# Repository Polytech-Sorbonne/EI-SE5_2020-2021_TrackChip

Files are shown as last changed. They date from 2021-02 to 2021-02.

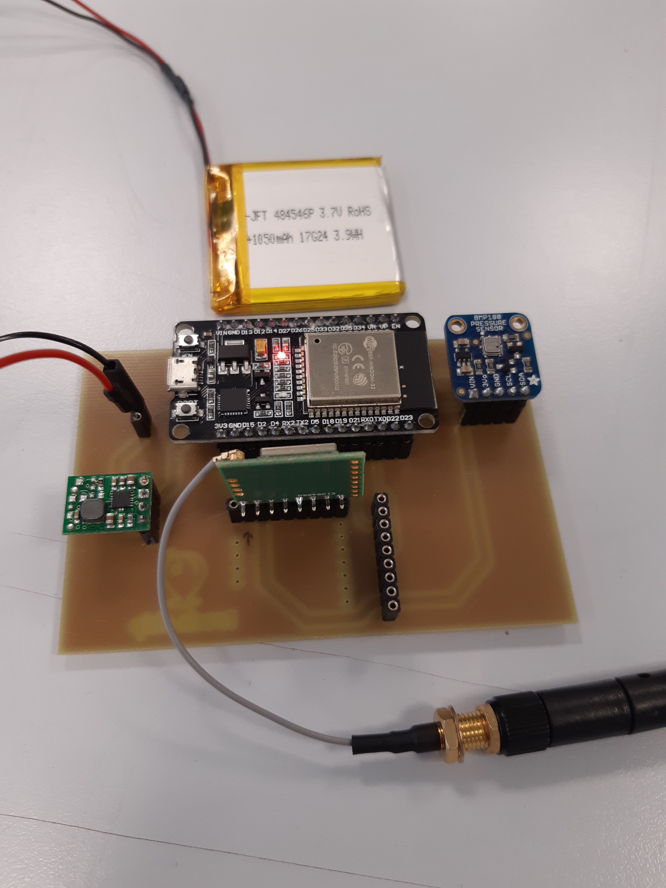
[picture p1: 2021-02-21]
ressources/pictures/pcb_front2.jpg

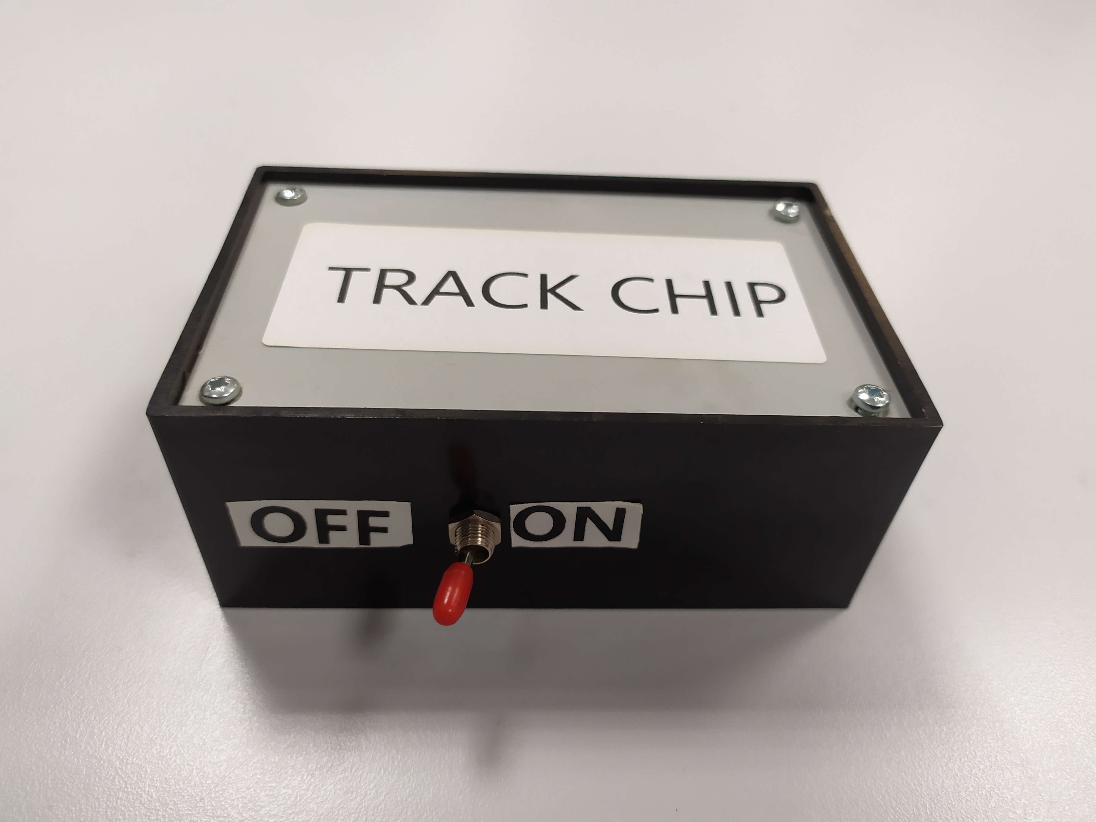
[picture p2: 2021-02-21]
ressources/pictures/integrated_system.jpg

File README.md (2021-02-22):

# TrackChip, le traqueur autonome ! 
L'objectif de ce projet est double :
* Développer un traqueur autonome de précision ~10m (partie Device)
* Récupérer ces informations sur un client WEB (partie Cloud)

### Device
Le device en lui-même est basé sur un micro-controleur ESP32, entouré des périphériques suivant :
* Altimètre BMP180
* GPS ADA746
* Module Sigfox BRKWS01
* Batterie LIPO 1050mAh
* Régulateur de tension 5V Polulu U1V11F5

```
Les sources des bibliothèques des périphériques ainsi que du PCB sont disponibles dans le dossier /devices du git.
```
### Site Web
Le site internet possède les fonctionnalitées suivantes :
* Position de l'utilisateur
* Position du traqueur
* Calcul de la différence d'altitude
* Calcul du trajet en voiture pour rejoindre le traqueur
* Historique des positions du traqueur

```
Les sources du serveur, de la base de donnée et du site Web sont disponibles dans la partie cloud/ du git.
```

# Notice d'utilisation
Le système dans son ensemble possède le comportement suivant :
* Le device utilise le GPS quand il reçoit un signal
* Le device utilise le scrapping WiFi quand le GPS est indisponible
* La position est envoyée sur notre serveur via le réseau SigFox
* Les informations sont accessibles sur notre site via un client Web. 

### Device
Le device s'allume et s'éteint avec le boutton ON/OFF sur le côté de sa boîte protectrice.
Il envoie alors sa position toutes les 5 minutes.
```
Le programme faisant fonctionner le device peut-être modifié et téléversé avec l'IE Arduino.
Il faut simplement s'assurer que les librairies utilisées sont bien visibles en les ajoutant dans ~/Arduino/lib.
```

### Réseau SigFox
Le device envoie ses données sur un backend web en utilisant le réseau SigFox.
Ce backend redirigie ensuite ces informations sur notre serveur grâce à une fonction de callback.
On accède au backend via l'URL suivant :
```
https://backend.sigfox.com/auth/login
```

### Serveur
Le serveur est un ensemble de programmes gérant le site Web ainsi que la base de donnée. 
Il peut être hebergé sur une machine locale, ou bien sur internet via un VPS.
Afin d'avoir accès aux nombreux service de géolocalisation (carte, itinéraire, etc), nous avons utilisé différentent APIs fournit par Google.
Ces APIs nécéssitent une clés pour pouvoir y accéder que vous devrez générer en créant d'abord un compte Google Cloud Platform. 
Puis en copiant, collant votre clés à la place de la notre dans le fichier dev/cloud/php/map.php à la ligne 44 dans le lien du script.
En local, on peut lancer le site avec les commandes suivantes :
```
$ cd /path/to/sources
$ php -S 127.0.0.1.:8888
```

### Site Web
Nous avons choisi d'utiliser l'hébergeur always-data pour notre site.
Cela donnait un URL du type :
```
https://track-chip.alwaysdata.net/
```

# Démonstration

Nous avons réalisé une petite vidéo de démonstration pour notre projet que vous pouvez visionner via les liens suivants : 
```
https://youtu.be/R3p7xfixrZM
https://drive.google.com/file/d/12YnQqh70TEWXKH5hvB63JBAPzKjCPeCU/view?usp=sharing
```

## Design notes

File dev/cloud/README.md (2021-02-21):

# Procédure à suivre pour se connecter au site

Ouvrir un navigateur internet (Chrome ou Chromium de préférence, ne fonctionne pas sur Safari) et taper l'adresse suivante : 
```
https://track-chip.alwaysdata.net/cloud/php/map.php
```

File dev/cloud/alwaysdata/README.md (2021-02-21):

# Procedure à suivre pour créer une cles SSH sur le serveur AlwaysData

## Etape 1 :

Générer la clé en local.
		
		$ mkdir -p $HOME/.ssh
		$ chmod 0700 $HOME/.ssh
		$ ssh-keygen -t ed25519 -f $HOME/.ssh/id_ed25519
		
		(tips : vous pouvez indiquez une passphrase vide pour pouvoir vous connecter directement sans la rentrer)

## Etape 2 :

Déclarer la clés publique (.pub) sur le serveur.

		$ ssh-copy-id -i $HOME/.ssh/id_ed25519.pub track-chip@ssh-track-chip.alwaysdata.net

## Etape 3 :

Se connecter au serveur en ssh.

		$ ssh track-chip@ssh-track-chip.alwaysdata.net

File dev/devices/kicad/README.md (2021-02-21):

# KiCad - Architecture

## Librairie
```
Le fichier track_chip.lib contient tout les "symboles" créés pour le projet :
	- ESP32 NodeMCU
	- BMP180
	- ADA746
	- BRKWS01

La librairie contient aussi les symboles déjà présents par défaut dans KiCad, 
afin d'éliminer la dépendance à la version du logiciel.
```

## Schéma
```
Le fichier .sch représente le schéma du circuit électronique du système (Eeschema).
Il instancie les différents symboles de la librairie du projet.
```

## Empreintes

### Dimensions
```
- Largeur typique d'une piste : 1mm
- Largeur typique d'une alimentation : 2mm
- Ecart entre les pastilles : 2.54mm
- Diamètre typique de perçage : 0.8mm
- Diamètre typique de pastille : 1.5mm
```

### Plans de masse
```
Recommendations : faire des plans de masses.
Si il y a un domaine analogique et un domaine numérique, 
faire des plans de masse séparés et les relier avec une piste.
```

## Batterie
```
On utilise un circuit avec chargeur intégré.
```
# Version Sigfox
La version Sigfox utilise un module Wisol pour les communications.
C'est cette version qui a été retenue pour les démonstrations

# Version GSM
La version GSM utilise une carte SIM pour les communications.
Cette version est en cours de développement.

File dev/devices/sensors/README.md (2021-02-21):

# Sensors
```
Dossier contenant les librairies pour les différents capteurs.
```

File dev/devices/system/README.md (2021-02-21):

# Classe track_chip
Classe encapsulant les librairies pour les différents périphériques.
(Communication, capteurs, position etc ...)

# Précaution lors de l'upload du code 
Il faut débrancher le broche TX du GPS pour pouvoir téléverser le code depuis l'IDE arduino.
C'est parce que ce gps utilise le même port série que le calbe USB utilisé pour téléverser.

# Architecture du code 
* On utilise la liaison _Serial_ pour imprimer des caractères sur la liaison USB

* Le gps communique avec la liaison _Serial1_ sur les broches RX0 et TX0 de l'ESP32
	+ BAUDE=9600 par défaut

* Le wisol communique avec la liaison _Serial2_ sur les broches RX2 et TX2 de l'ESP32 
	+ BAUDE=9600 par défaut

# examples/class_system/
Ce dossier instancie un code example utilisant la classe track_chip
(En cours de développement)

# examples/bare_system/
Ce dossier instancie un code example utilisant les libairies sans la classe track_chip

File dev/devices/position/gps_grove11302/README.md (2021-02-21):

# Module GPS Grove

Le dossier grove11302/ contient une librairie Arduino pour l'utilisation du module GPS Grove 11302..
Pour utiliser cette librairie, compresser ce dossier en .zip puis l'ajouter dans l'IDE dans sketch -> include librairy

Le dossier examples/ contient 2 codes sources Arduino permmetant d'imprimer sur une liaison série les données brut provenant du module GPS puis uniquement la ligne de donnée comportant les coordonnées en DMS (degrés , minutes, secondes).

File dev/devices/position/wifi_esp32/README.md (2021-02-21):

# Fonctions de localisation grâce aux réseaux Wifi
```
Ces fonctions ont été recopiées et intégrées à la classe TrackChip.
```

# Installation instructions using Arduino IDE Boards Manager
```
- Stable release link: `https://raw.githubusercontent.com/espressif/arduino-esp32/gh-pages/package_esp32_index.json`
- Development release link: `https://raw.githubusercontent.com/espressif/arduino-esp32/gh-pages/package_esp32_dev_index.json`

Starting with 1.6.4, Arduino allows installation of third-party platform packages using Boards Manager. We have packages available for Windows, Mac OS, and Linux (x86, amd64, armhf and arm64).

- Install the current upstream Arduino IDE at the 1.8 level or later. The current version is at the [Arduino website](http://www.arduino.cc/en/main/software).
- Start Arduino and open Preferences window.
- Enter one of the release links above into *Additional Board Manager URLs* field. You can add multiple URLs, separating them with commas.
- Open Boards Manager from Tools > Board menu and install *esp32* platform (and don't forget to select your ESP32 board from Tools > Board menu after installation).
```

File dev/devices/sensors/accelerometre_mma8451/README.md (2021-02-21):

# Accéléromètre MMA8451

## BUS I2C
```
Deux fils (SDA, SCL) tirés à 5V.

I2C utilise des séquences de 8 bits (MSB first = Big Endian)

Start - slave_addr - A - slave_reg - A - Data - A - Stop

Start	: SDA drops low, SDC still high
ACK	: le slave tire la ligne SDA à zéro
Stop 	: SDA low -> high ; SCL high
```

## Librairie utilisée
```
https://github.com/adafruit/Adafruit_MMA8451_Library
```

## Packager la librairie modifiée
```
Créer un lien symbolique du dossier mma8451/ dans Arduino/libraries :
$ cd ~/Arduino/libraries
$ ln -s /path/to/mma8451
```

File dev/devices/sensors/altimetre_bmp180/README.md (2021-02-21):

# Altimètre BMP180

## BUS I2C
```
Deux fils (SDA, SCL) tirés à 5V.

I2C utilise des séquences de 8 bits (MSB first = Big Endian)

Start - slave_addr - A - slave_reg - A - Data - A - Stop

Start	: SDA drops low, SDC still high
ACK	: le slave tire la ligne SDA à zéro
Stop 	: SDA low -> high ; SCL high
```

## Librairie utilisée
```
https://bitbucket.org/christandlg/bmp180mi/src/master/
```

## UML
```
Cette librairie possède le diagramme UML suivant :
		BMP180MI 
		   |
		   |
	     BMP180TwoWire 
		   |
		   |
	       BMP180I2C

On se contente donc de modifier la classe fille BMP180I2C
```

## Packager la librairie modifiée
```
Créer un lien symbolique du dossier bmp180/ dans Arduino/libraries :
$ cd ~/Arduino/libraries
$ ln -s /path/to/bmp180
```

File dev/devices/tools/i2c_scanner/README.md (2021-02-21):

# Scanner I2C
```
Ce code (tiré du site d'Arduino) permet de scanner les différents périphériques I2C.
Dès qu'un périphérique est branché au BUS I2C de notre µControleur, ce code affiche son addresse 0x...
```

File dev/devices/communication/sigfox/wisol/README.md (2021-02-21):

Guide Utilisation librairie Wisol
developpée pour module Wisol Sigfox et ESP32 
Pour utiliser la librairies :
compresser le dossier wisol au format .zip puis ajouter depuis l'IDE: sketch > include library

Pour utiliser l'example sans mdofications :
TX (wisol) -> RX2 (esp32)
RX (wisol) -> TX2 (esp32)
+ (wisol) -> 3.3V (esp32)
- (wisol) -> GND (esp32)

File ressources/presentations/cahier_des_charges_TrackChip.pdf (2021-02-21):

Cahier des Charge : TrackChip

- Contexte

Ce projet se déroule dans le cadre de notre 5ᵉ année au sein de l'école d'ingénieurs Polytech Sorbonne, en spécialité électronique et informatique embarquée. Nous devons donc ici développer un objet connecté répondant à un problème concret.

- Cas d’usages

Le but est de pouvoir localiser précisément votre bagage, votre véhicule ou bien même des personnes partout dans le monde ce qui pourrait être une bonne solution en cas de vol ou de perte.

De plus, avec l’explosion du commerce en ligne et la dématérialisation des espaces de travail, les envois de colis se sont multipliés. Il existe une part d’ombre à ce phénomène : les colis volés et perdus ou endommagés. Les entreprises communiquent peu sur le sujet mais on estime à 1.5 millions de colis traités par La Poste qui "disparaissent" chaque année. Ce n’est guère mieux pour Amazon où 17% des produits arrivent endommagés chez le client. Dans le cadre d’objets fragiles et/ou de grande valeurs marchande, placer un boîtier enregistrant les déplacements et les chocs subis par un paquet permet au livreur ou au vendeur de localiser la précieuse cargaison et de documenter les conditions de transport pour améliorer l’acheminement.

- Acteurs

Étudiants : Thomas Bouix, Aziz Idomar, Enzo Calvino, Eugène Raphanel Référent : Roselyne Chotin
Support Technique : Sylvain Viateur
- Nom du projet
TrackChip, le traqueur de poche !
- Besoins
- Localiser précisément un bagage / colis
- Connaître la vitesse de ce bagage / colis
- Connaître l’altitude de ce bagage / colis
- Connaître les collisions subit par ce bagage / colis

- Matériel nécessaire

Micro-Controlleur :

- ESP32 (https://www.gotronic.fr/art-module-nodemcu-esp32-28407.htm)

Communication :
- Module Wisol SigFox

Capteurs :

- GPS (https://www.gotronic.fr/art-module-gps-ada746-20694.htm)
- Altimètre (https://www.gotronic.fr/art-capteur-de-pression-mpl3115a2-20239.htm#complte_desc)
- Accéléromètre (https://www.gotronic.fr/art-accelerometre-et-gyroscope-3-axes-sen-mpu6050-31492.htm)

Alimentation :

- Batterie (https://www.gotronic.fr/art-accu-lipo-3-7-vcc-4000-mah-l805080-31843.htm)
- États de l’art
- Solutions déjà existantes
Spotter : 90€ + Abonnement (5€/mois)
→ Géolocalisation, appels, zone de sécurité

Invoxia : 99 € avec application et assistance
→ Tracker GPS pour Véhicule, Personne et Objets Précieux
- Valeur Ajoutée
- Altitude, Collisions
- Prix du traqueur : proposer les mêmes fonctionnalités pour un prix inférieur.
- Minimal Viable Product
- Organisation

Nous allons réaliser le projet en suivant une méthode agile. Nous avons donc établi plusieurs étapes de notre produit qui seront de plus en plus développées au cours du projet. Pour chaque étape, nous avons rédigé des Users Stories, c'est-à-dire des petits cas d’usage qui seront développés de manières indépendante au cours d’un sprint.
Les étapes 1 et 2 correspondent au développement de notre MVP :

Etape 1 : Fonctionnement local
- Position, Altitude, Accélération dans un terminal
- US : récupérer l’altitude dans un terminal série.
- US : récupérer l’accélération dans un terminal série.
- US : récupérer la position avec le GPS
- US : faire le schéma électrique (Kicad)
- US : intégrer toutes les solutions (sur labdec)

Etape 2 : Communication avec l’extérieur
- Position, altitude et accélération en raw dans un site web html simple
- US : Définir la base de données (draw.io + fichier sql)
- US : Créer un serveur web simple pouvant récupérer des données (Framework + HTML)
- US : Configurer le backend SigFox
- US : Configurer la communication GSM
- US : Envoyer les données en utilisant Sigfox (vérifier avec printf ESP32)
- US : Envoyer les données en utilisant la communication GPRS
- US : Choix du protocole de communication en fonction des résultats
- US : Lier la base de donnée au site web
- US : Récupérer les données Sigfox / GPRS sur un serveur web
- US : Créer une carte électronique (PCB)
- US : Envoyer les données de la machine sur le serveur
- US : Intégrer les composants sur la carte

Pour déterminer notre MVP, nous avons fait la liste des fonctionnalités et usages pouvant être utiles à notre projet. Ensuite nous les avons classifiés selon 3 degrés d’importance. Les fonctionnalités en vert (voir ci-dessous) sont celles que nous jugeons indispensables et que nous allons donc intégrer au MVP.

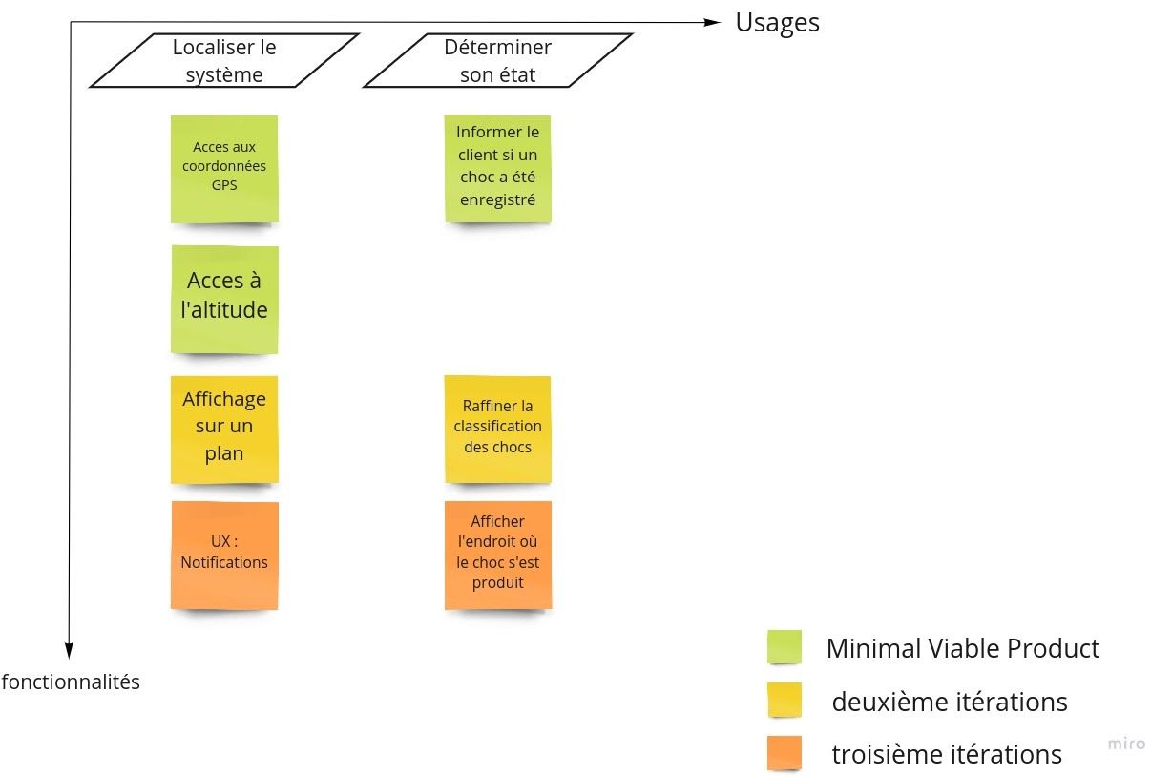
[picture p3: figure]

Usages et fonctionnalités du produit

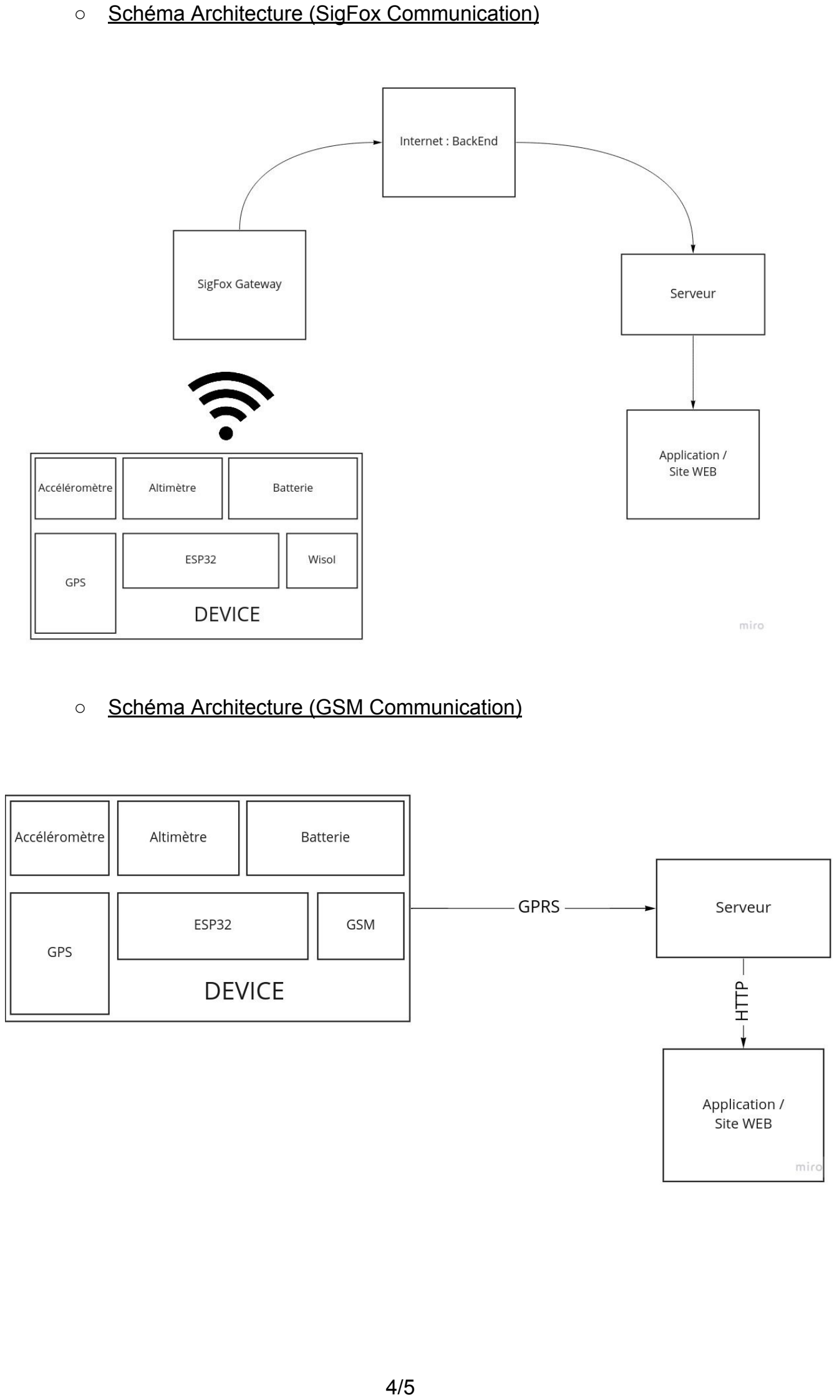
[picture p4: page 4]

- Schéma Architecture (SigFox Communication)
- Schéma Architecture (GSM Communication)

ANNEXE

Calcul théorique de la consommation

Approximation des consommation :
- ESP32 = 50 mA pendant 15s (3,8 mA avec clock ralentie)
- GPS = 20mA pendant 10s
- Wisol = 20mA pendant 15s
- Accéléromètre & Altimètre ~ 1 mA pendant 15s
- Système complet = 0 mA en veille

À une fréquence de 1 fois toutes les 10 minutes

Consommation par heure
= (50 mA*15s + 21mA * 15s + 20mA*10s) * 6
= 7,6As (ou 7,6C)

Avec une batterie de capacité 4Ah ou 4*3600C = 14,4kC Nombre d’heures de fonctionnement théorique :
Nbh = 14,4k / 7,6 = 1895h = 79j

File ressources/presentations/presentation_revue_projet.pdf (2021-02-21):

# Projet IOT Présentation d’un prototype

TrackChip, le traqueur de colis !

Eugène Raphanel, Enzo Calvino, Aziz Idomar, Thomas Bouix

II/ Présentation du projet

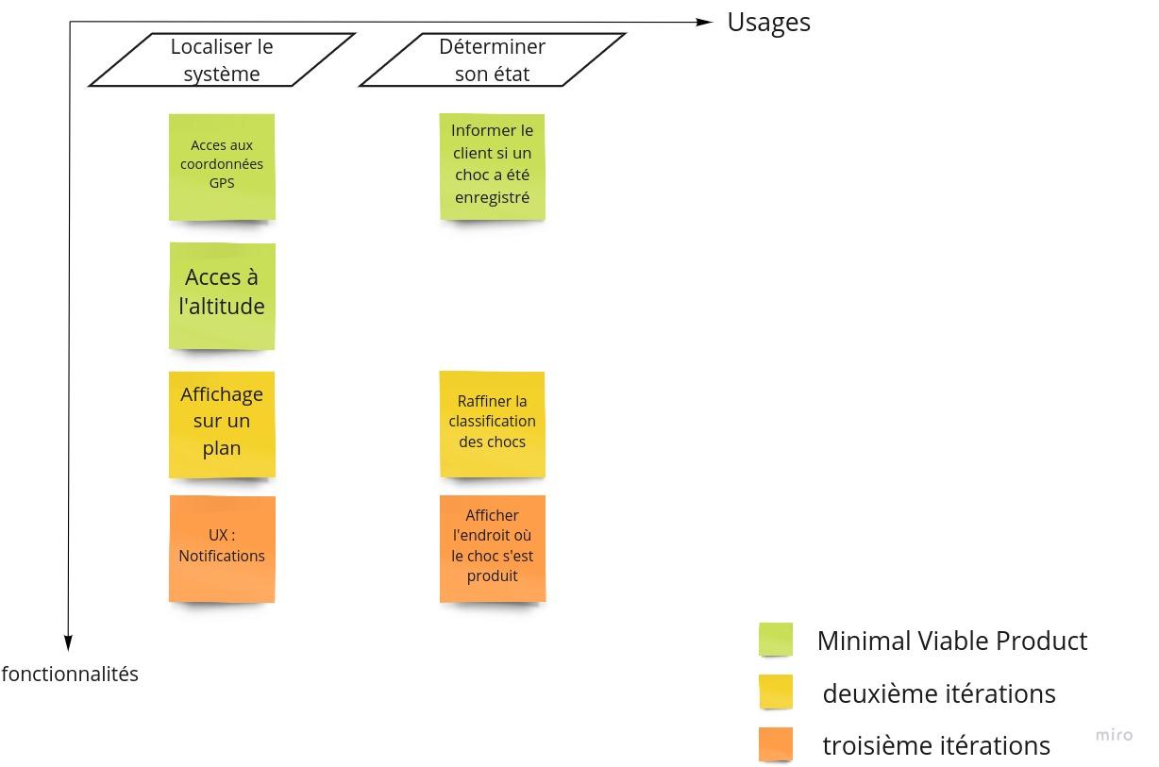
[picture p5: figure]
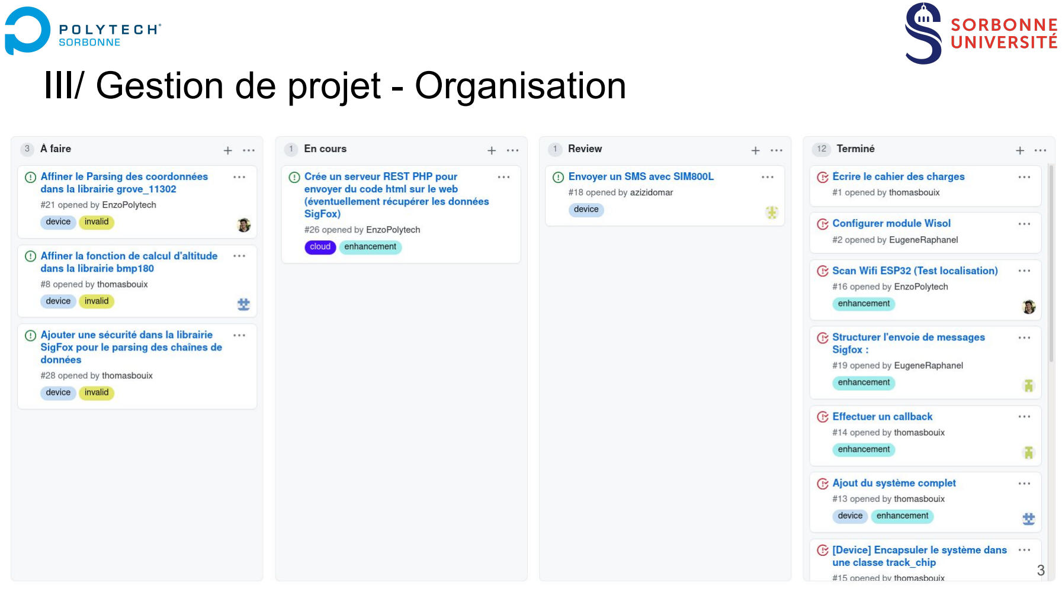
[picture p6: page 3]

III/ Gestion de projet - Organisation

IV/ Système - Partie “Device”

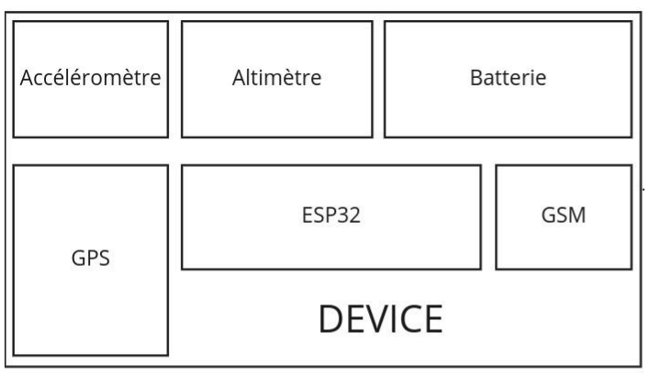
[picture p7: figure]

ESP32
Altimètre
Accéléromètre
GPS
GSM
Batterie

IV/ Système - Communication SigFox

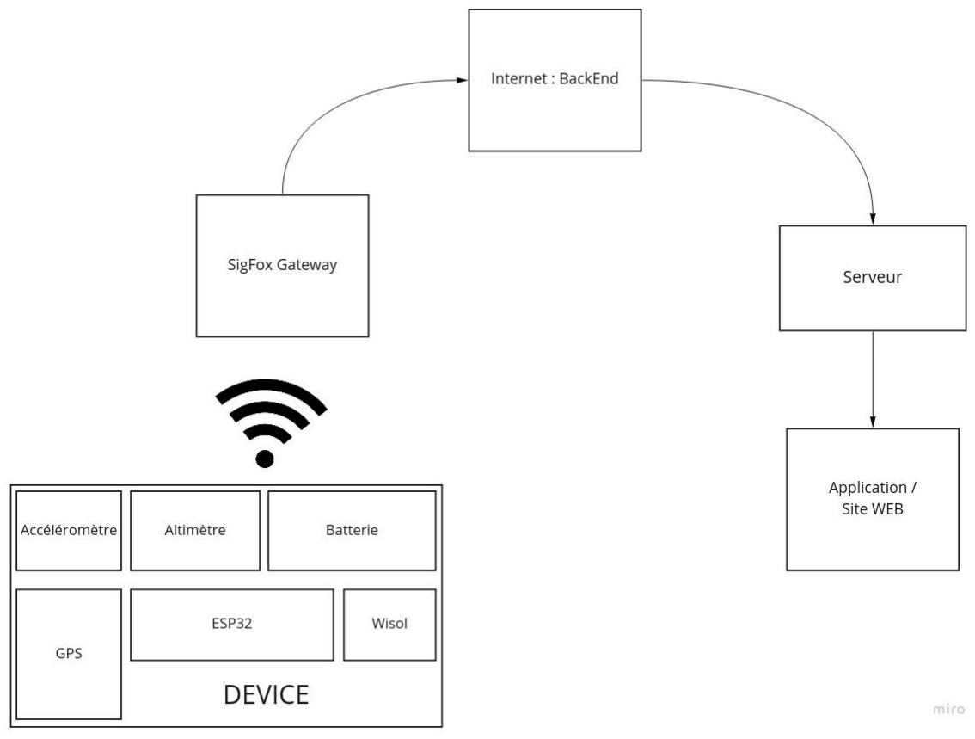
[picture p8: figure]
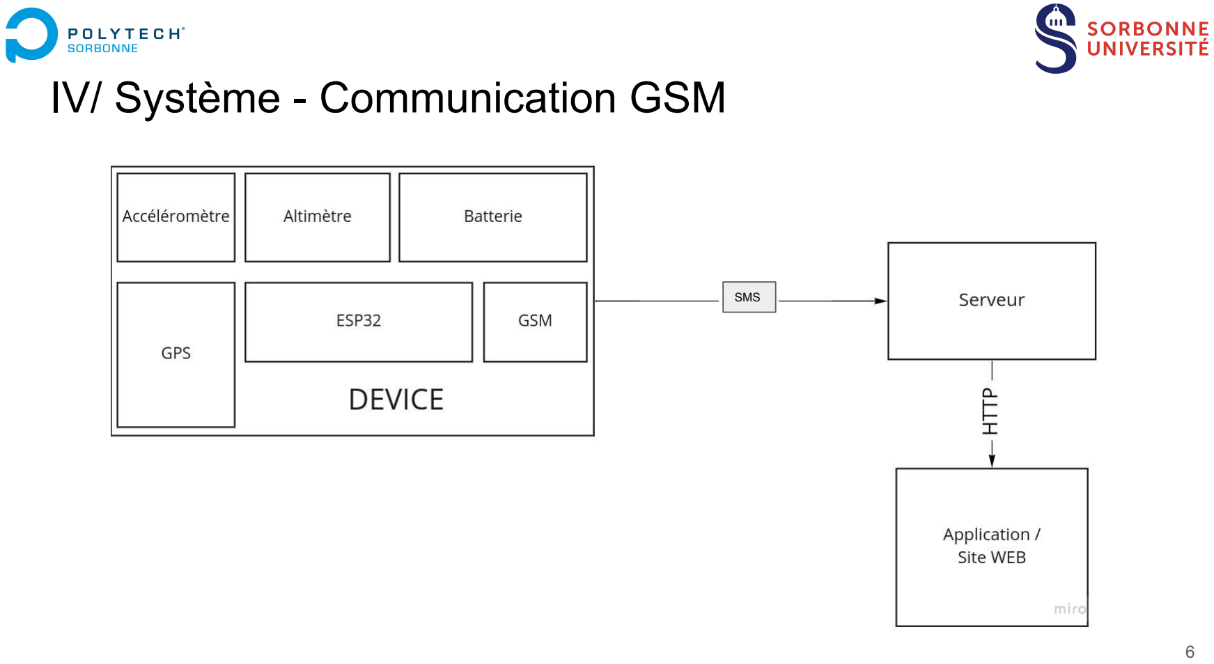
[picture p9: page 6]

IV/ Système - Communication GSM

SMS

IV/ Système - Partie “Cloud”

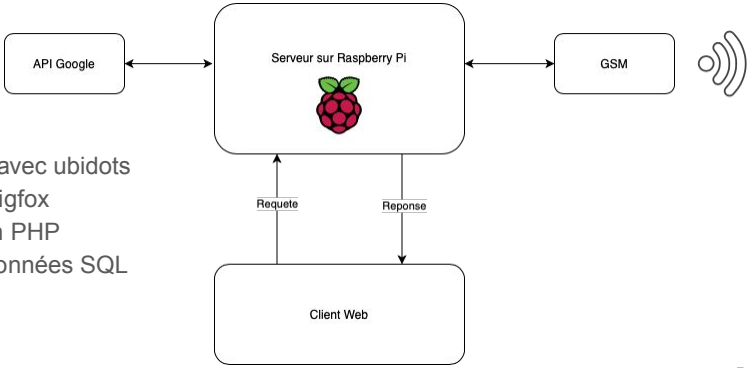
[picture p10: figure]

- Prototype avec ubidots
- Backend sigfox
- Serveur en PHP
- Base de données SQL

# Merci de votre attention !

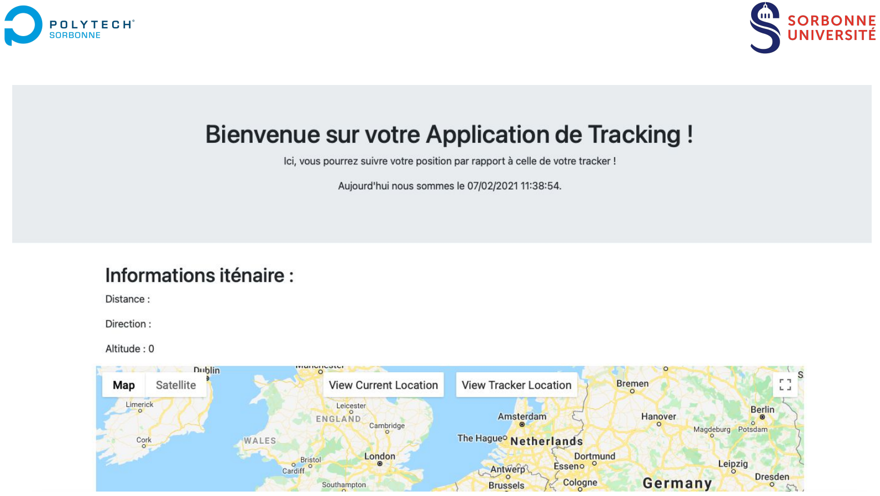
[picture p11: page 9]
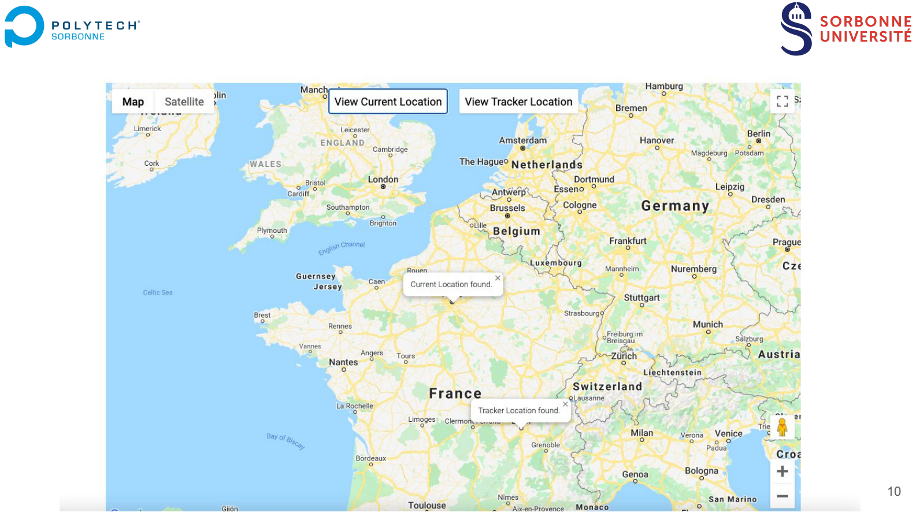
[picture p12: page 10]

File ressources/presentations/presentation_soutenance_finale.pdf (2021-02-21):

# Projet IOT Présentation finale

## TrackChip, le traqueur autonome !

Eugène Raphanel, Enzo Calvino, Aziz Idomar, Thomas Bouix

## I/ Introduction et motivations

Projet IOT | Dualité device - cloud

Gestion de
projet

Développement d’un
objet connecté
répondant à un besoin
réel

Symbiose de l’
électronique et de
l’informatique dans un
système embarqué

Mise en pratique de la
gestion de projet en
utilisant la méthode agile

## II/ Présentation du projet

Fonctionnalités | Cas utilisateurs
Traqueur minimaliste | Traquer des colis
Autonomie de plusieurs mois en énergie | Traquer des personnes
Précision d’une dizaine de mètres | Traquer des véhicules

Informations affichées sur un site web

## II/ Présentation du projet

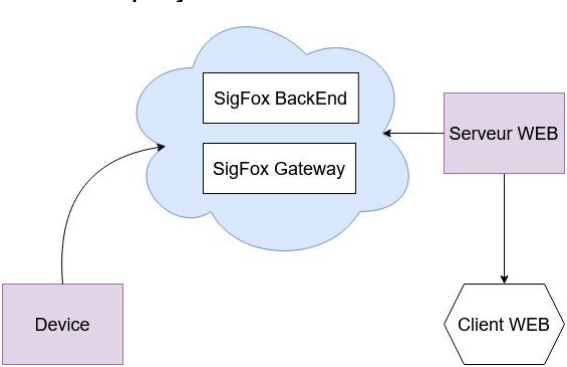
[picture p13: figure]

## III/ Partie Device - Présentation

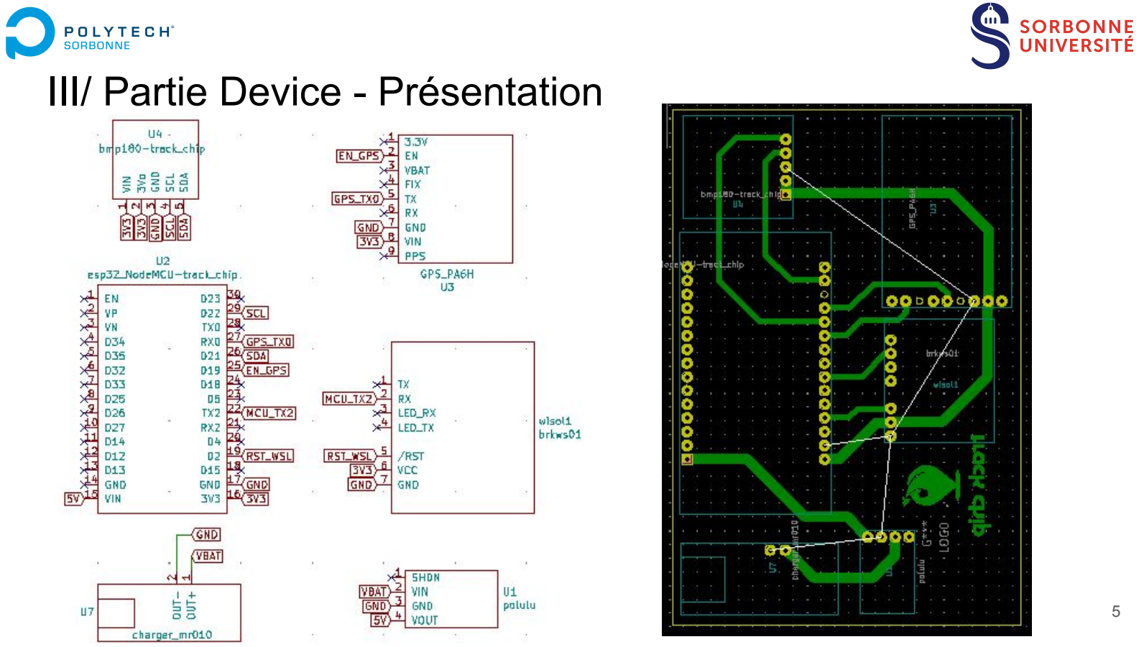
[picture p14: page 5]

## III/ Partie Device - PCB

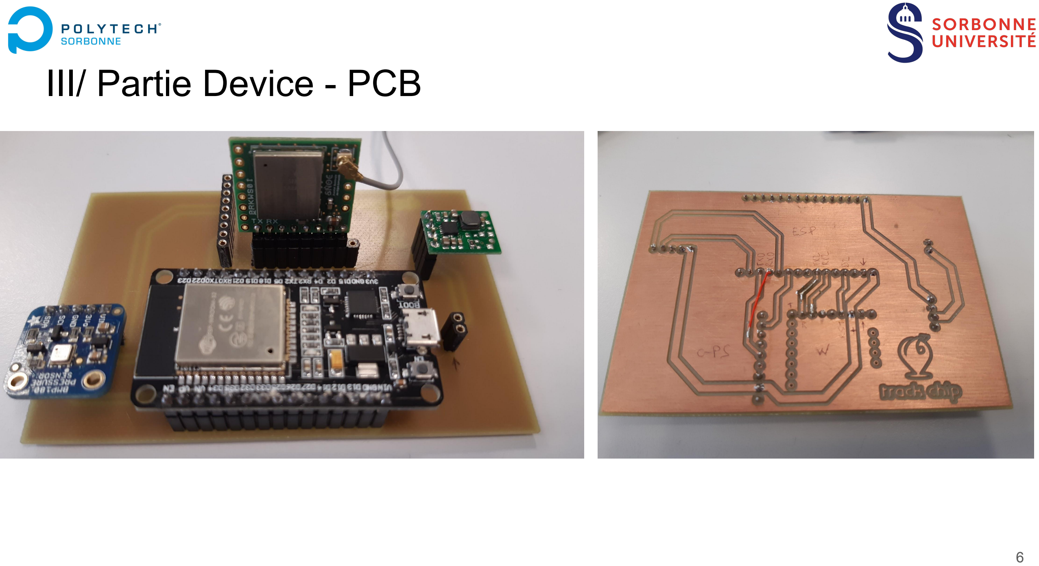
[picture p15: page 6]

## Lien Device/Cloud

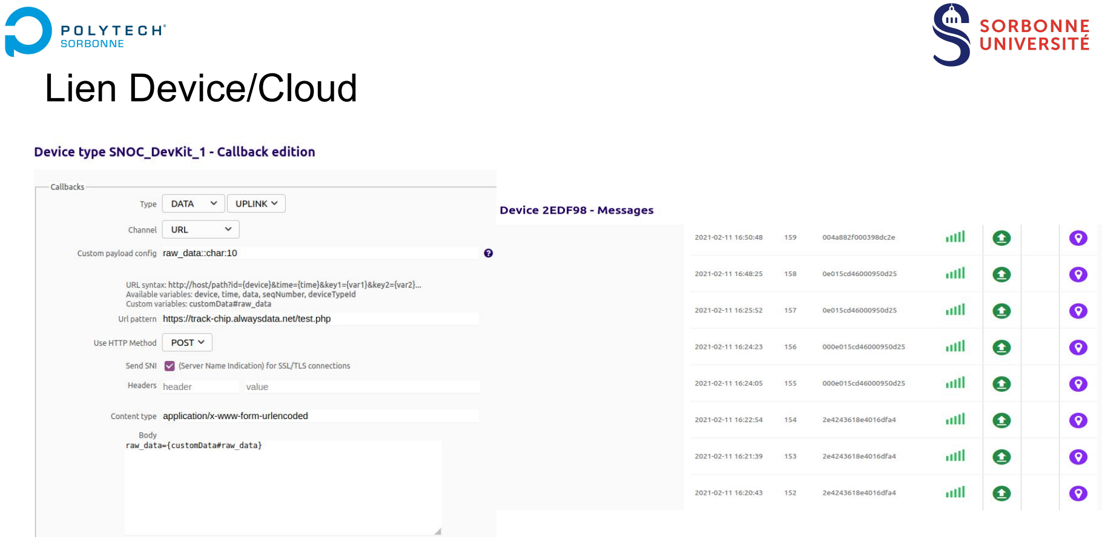
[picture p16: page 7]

7

## IV/ Partie “Cloud” - Présentation

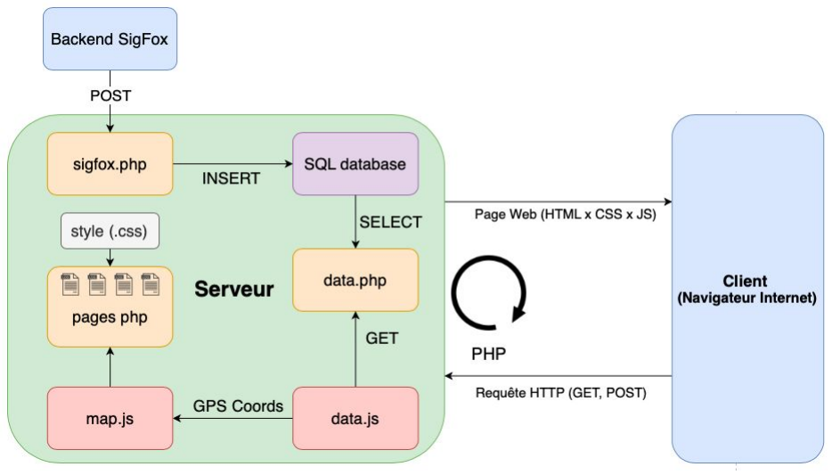
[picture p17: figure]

## IV/ Partie “Cloud” - Site Web

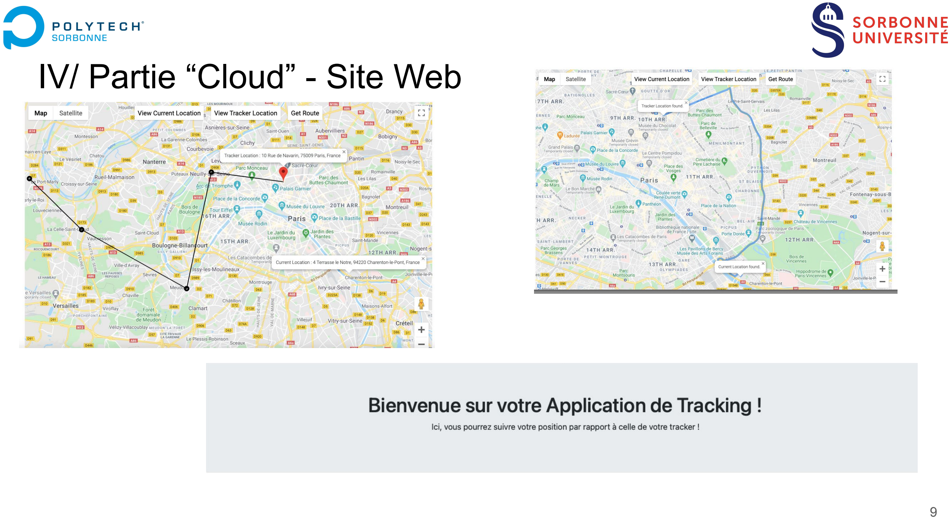
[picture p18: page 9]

présentation du site

## V/ Retour sur expérience et conclusion

10

Device | Cloud | Gestion de projet

Réutilisation du matériel
électronique
Révisions bus série + I2C
Réutilisation de KiCad
Soudures et débogage

Mise en pratique des
technologies du WEB (PHP,
Javascript, HTTP …)

Utilisation des outils GitHub (Issues, Projet …)
Utilisation des méthodes
agiles (Scrum, MVP, US …)

## VI/ Résultats et démonstration

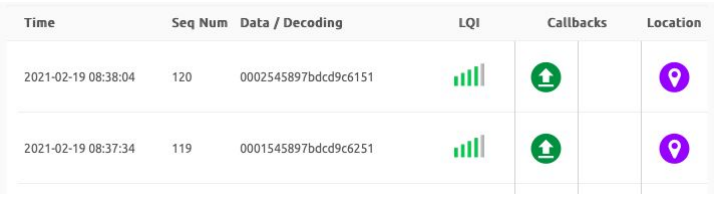
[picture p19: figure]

Le device envoie 2 messages sur le backend SigFox, caractérisant la position grâce au scrapping WiFi

## VI/ Résultats et démonstration

Le script sigfox.php reçoit les données
du callback SigFox et les insère dans la base de données

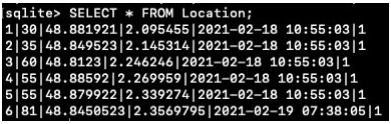
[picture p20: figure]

Depuis le serveur, on lit ces informations dans la base de données

## VI/ Résultats et démonstration

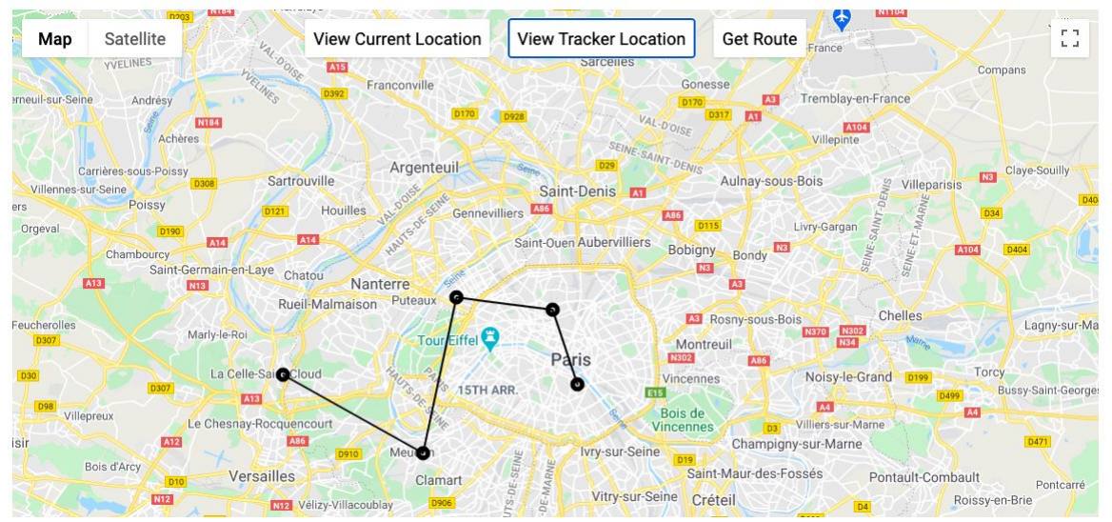
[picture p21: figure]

Via un client WEB, on peut suivre l’historique des positions et un itinéraire pour rejoindre le traqueur

# Merci de votre attention !

## Annexe - Gestion de projet

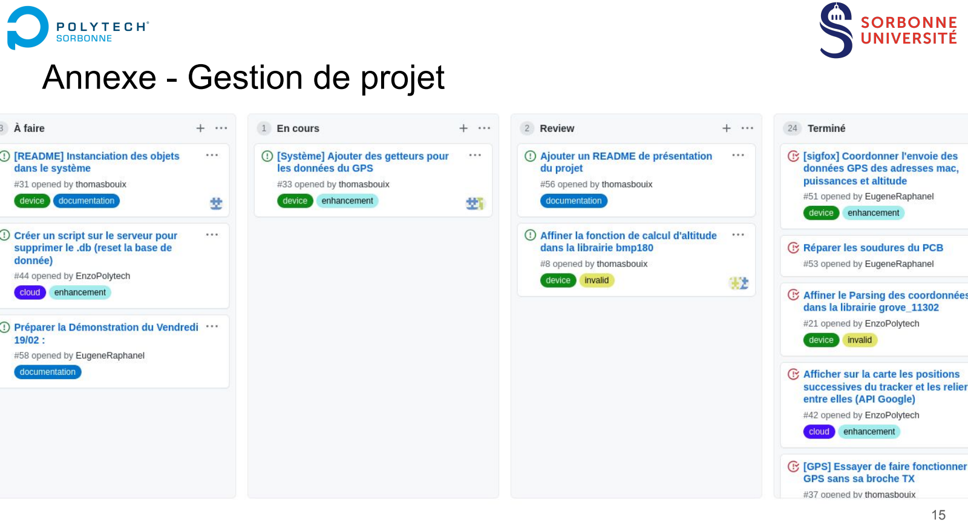
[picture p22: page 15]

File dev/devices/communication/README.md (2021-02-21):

# Communications
```
Dossier contenant les librairies pour les différents périphériques de communication.
```

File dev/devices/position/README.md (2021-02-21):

# Position 
```
Dossier contenant les librairies pour les différents périphériques de position.
```

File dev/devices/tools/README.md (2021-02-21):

# Tools
```
Dossier contenant les différents outils de debug.
```

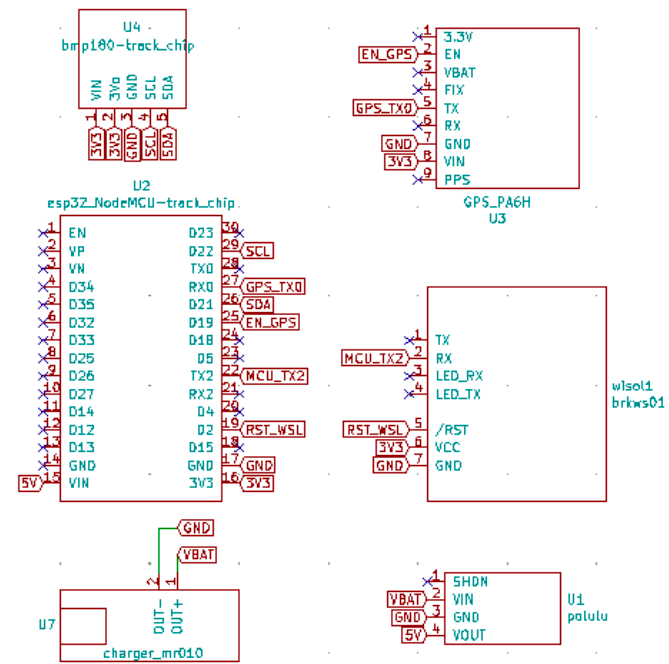
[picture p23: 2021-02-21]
ressources/schemas/kicad_schematic.png

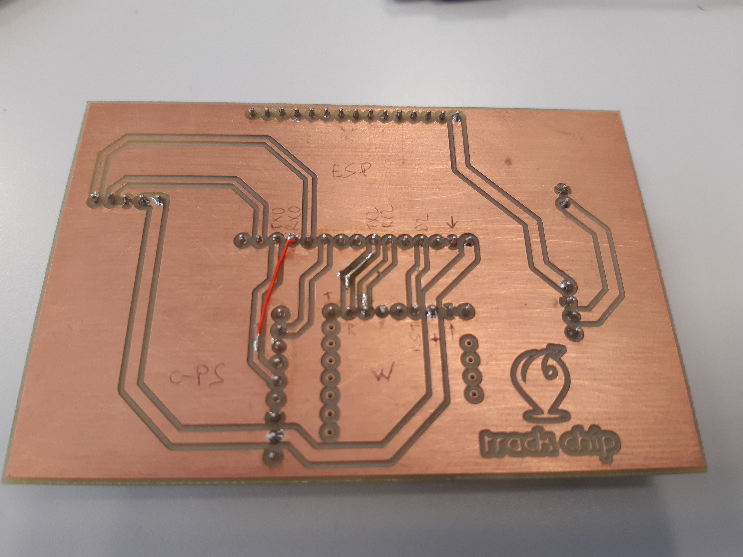
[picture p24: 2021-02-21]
ressources/pictures/pcb_back2.jpg

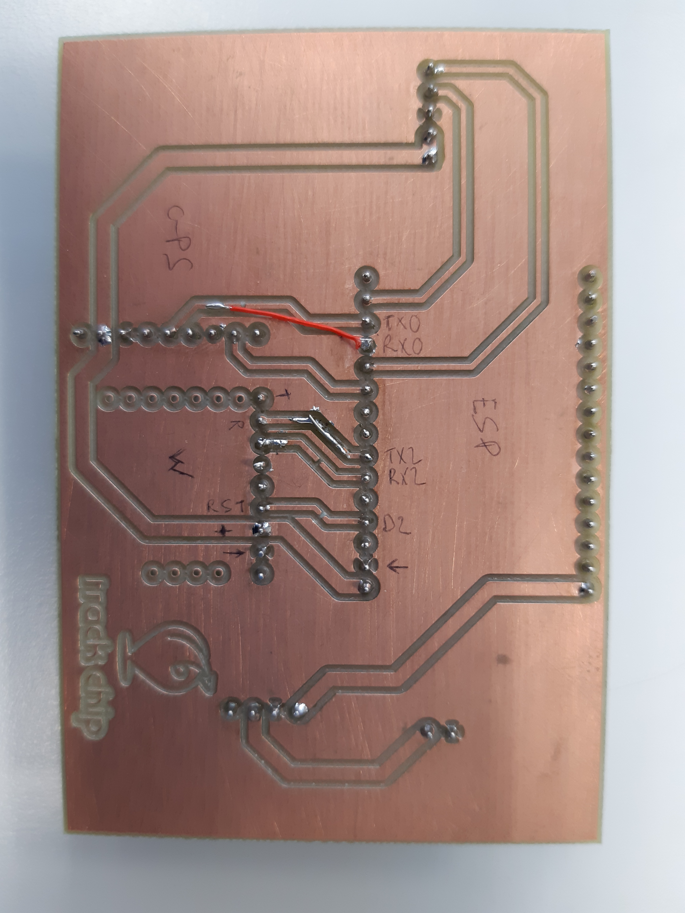
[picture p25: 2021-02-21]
ressources/pictures/pcb_back1.jpg

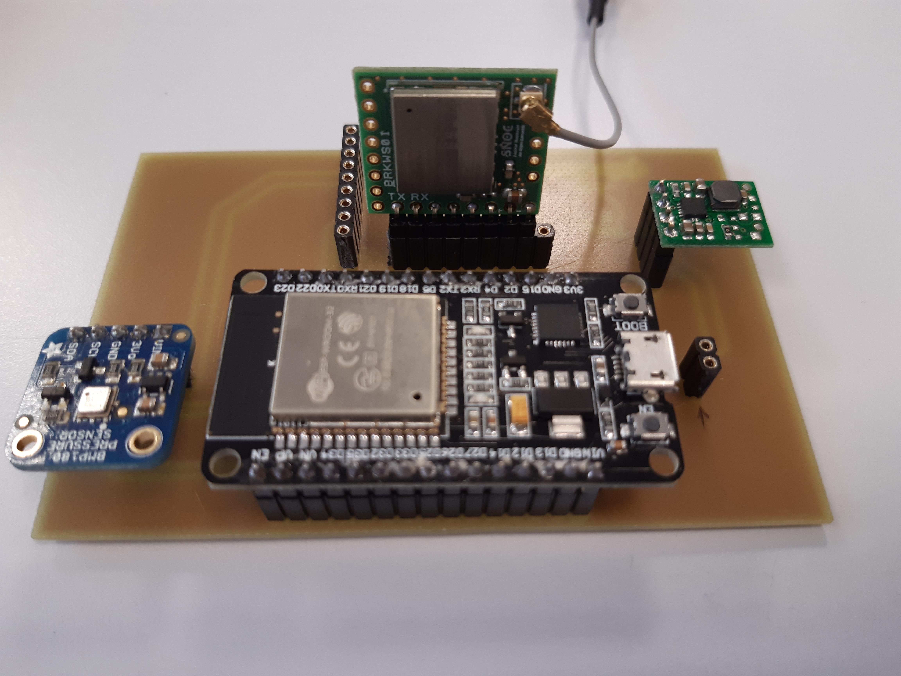
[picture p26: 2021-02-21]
ressources/pictures/pcb_front1.jpg

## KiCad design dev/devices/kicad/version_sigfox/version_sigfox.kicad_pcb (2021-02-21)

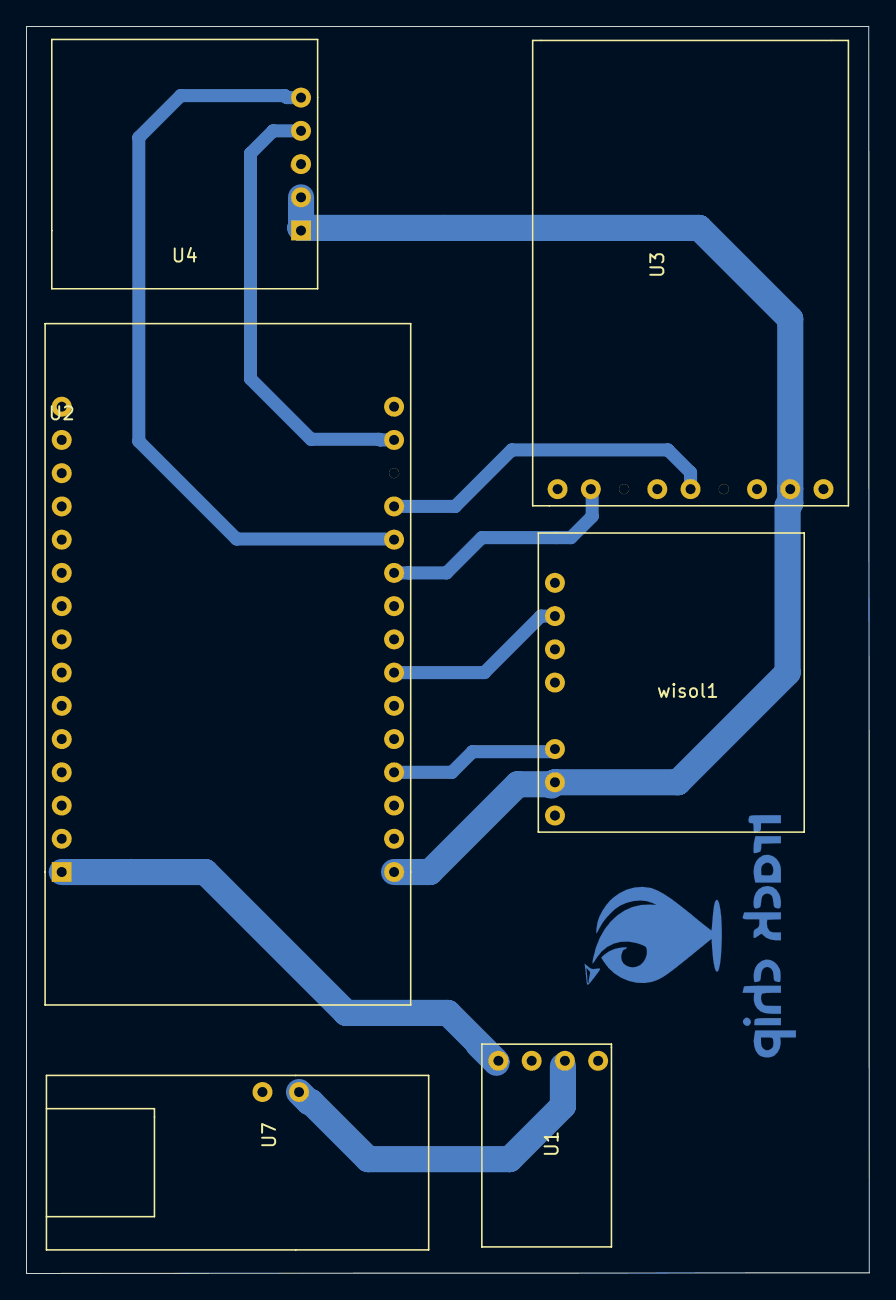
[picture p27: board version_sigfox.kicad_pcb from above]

Board: 2 copper layers, 64.4 x 95.3 mm, 6 parts (0 on the bottom side), 10 nets.

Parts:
U1: polulu
U2: esp32_NodeMCU-track_chip; esp32
U3: GPS_PA6H
U4: bmp180-track_chip; bmp180
U7: charger_mr010
wisol1: brkws01; BRWS01

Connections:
3V3: U2.16, U3.8, U4.1, U4.2, wisol1.6
5V: U1.4, U2.15
EN_GPS: U2.25, U3.2
GND: U1.3, U2.17, U3.7, U4.3, U7.2, wisol1.7
GPS_TX0: U2.27, U3.5
MCU_TX2: U2.22, wisol1.2
RST_WSL: U2.19, wisol1.5
SCL: U2.29, U4.4
SDA: U2.26, U4.5
VBAT: U1.2, U7.1

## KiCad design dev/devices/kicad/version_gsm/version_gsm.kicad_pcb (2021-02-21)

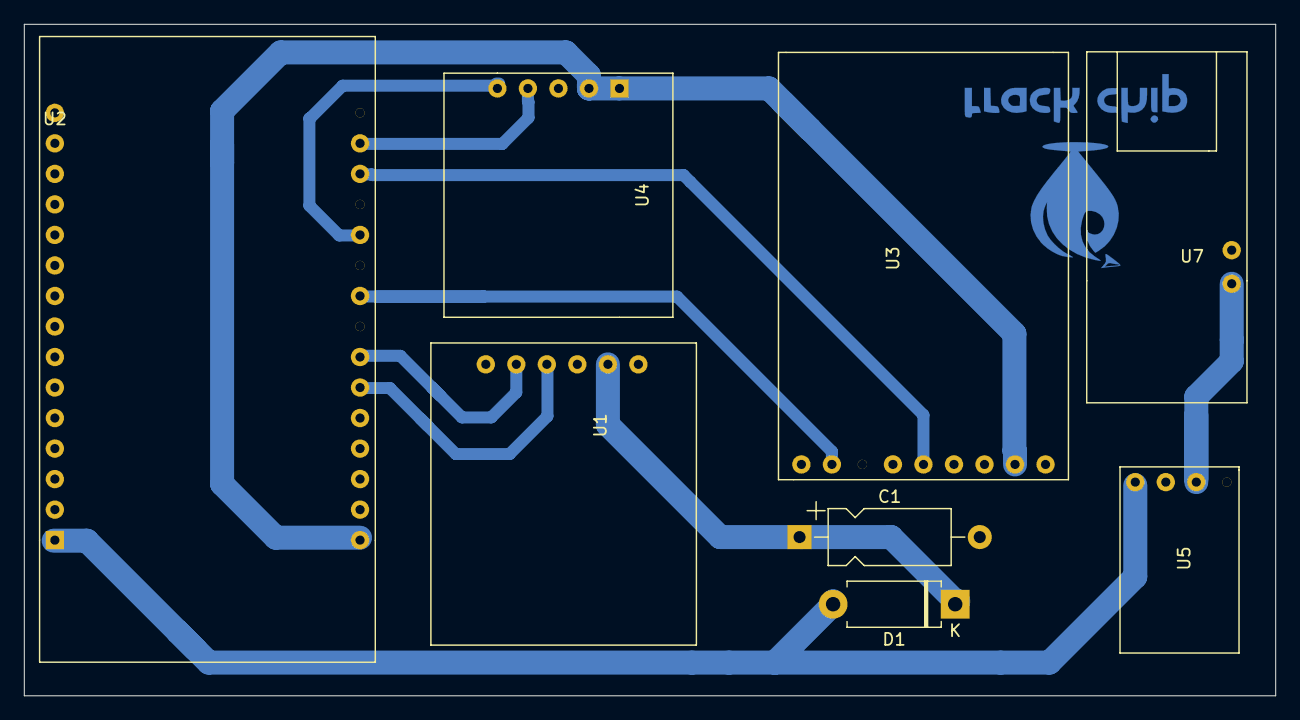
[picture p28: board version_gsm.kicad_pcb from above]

Board: 2 copper layers, 104.1 x 55.9 mm, 8 parts (0 on the bottom side), 11 nets.

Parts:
C1: 100u; CP_Axial_L10.0mm_D4.5mm_P15.00mm_Horizontal
D1: 0.8V; D_DO-15_P10.16mm_Horizontal
U1: SIM800L
U2: esp32_NodeMCU-track_chip; esp32
U3: GPS_PA6H
U4: bmp180-track_chip; bmp180
U5: polulu
U7: charger_mr010

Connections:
3.3V: U2.16, U3.8, U4.1, U4.2
5V: D1.2, U2.15, U5.4
EN_GPS: U2.24, U3.2
GND: C1.2, U1.6, U2.17, U3.7, U4.3, U5.3, U7.2
unnamed: C1.1, D1.1, U1.2
RX2: U1.4, U2.21
SCL: U2.29, U4.4
SDA: U2.26, U4.5
TX0: U2.28, U3.5
TX2: U1.5, U2.22
VBAT: U5.2, U7.1

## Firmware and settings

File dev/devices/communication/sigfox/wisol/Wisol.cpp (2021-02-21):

/*
Librairie permettant d'envoyer une chaine de caractère de 12 octets d'un ESP32 vers un module Sigfox Wisol
*/
#include "Wisol.h"

//Constructor
Wisol::Wisol(int baudrate, int RX, int TX){
	Serial2.begin(baudrate, SERIAL_8N1, RX, TX);
	while (!Serial2);
}

Wisol::Wisol(){
	Wisol(9600, RX2, TX2);
}

//private function
bool Wisol::IsHexCharOrNewLine(char c){
	return (c >= '0' && c <= '9') ||
		(c >= 'A' && c <= 'F') ||
		(c >= 'a' && c <= 'f') ||
		c == '\n'; // You may want to test for \r as well
}

bool Wisol::IsHex(char* text){
	bool temp = true;
	for (int i = 0; i < strlen(text); i++){
		temp = temp && IsHexCharOrNewLine(text[i]);
	}
	return temp;
}

bool Wisol::string_ok(String verif){
	//verifier que la string fait moins de 12 octets
	int n = verif.length() ;
	if (n > 24) {
		Serial.println("string too long");
		return false;
	}
	char char_array[n + 1];
	strcpy(char_array, verif.c_str());
	//qu'elle ne contient que des caractères Hexa
	return IsHex(char_array);
}

//public function
void Wisol::send_string_data(String envoie) {

	Serial.println("Wisol::send_string_data => envoie = " );
	Serial.println(envoie);

 	if (string_ok(envoie)) {
		Serial.println("Wisol::send_string_data => string is valid" );
		String command = "AT$SF=";

		command = command + envoie;
		Serial.print("Wisol::send_string_data => sending : " );
		Serial.println(command);
		Serial2.println(command);

	} else {
		Serial.println("Wisol::send_string_data => string is not valid" );

	}
}

String Wisol::double_to_hexa(double a, int prec){
	String message = "";
	int temp;
	temp = double_to_int(a, prec);
	message = int_to_hexa(temp);
	return message;
}

String Wisol::int_to_hexa(int a){
	char hex_string[20];
	sprintf(hex_string, "%X", a); //convert number to hex
	return hex_string;
}


int Wisol::double_to_int(double a, int prec){
	int res = round(a*pow (10, prec));
	return res;
}


// convertis aussi bien la latitude que la longitude. Cette fonction suppose que le paramètre cardinal est N, S, E ou O.
double Wisol::Dms_to_dd(char cardinal, int angle, int minute, double seconde){
	double res = angle;
	double temp = seconde/60;
	res += (minute+temp)/60;

	if ( cardinal == 'S' || cardinal == 'O') {
		res = -res;
	}

	return res;
}

double Wisol::shift_latitude(double lat){
	return lat+180;
}

double Wisol::shift_longitude(double lng){
	return lng+90;
}

String Wisol::complete_hexa_bytes(String hexa, int nb_bytes){ // prend en argument une chaine hexa et le nombre d'octets voulu pour le callback et complete avec des 0 big edians
	int add = 2*nb_bytes - hexa.length();
	String complete = "";
	for(int i = 0; i<add;i++){
		complete = complete+"0";
	}
	return complete +hexa;
}

String Wisol::dms_lat_to_trame_hexa(char cardinal, int angle, int minute, double seconde,int prec){
	double dd = shift_latitude(Dms_to_dd(cardinal, angle, minute, seconde));
	String res_lat = Wisol::double_to_hexa(dd, prec);
	res_lat = complete_hexa_bytes(res_lat, 4);
	return res_lat;
}

String Wisol::dms_lng_to_trame_hexa(char cardinal, int angle, int minute, double seconde,int prec){
	double dd = shift_longitude(Dms_to_dd(cardinal, angle, minute, seconde));
	String res_lat = Wisol::double_to_hexa(dd, prec);
	res_lat = complete_hexa_bytes(res_lat,4);
	return res_lat;
}

String Wisol::altitude_to_trame_hexa(int altitude){
	String res_alt = Wisol::int_to_hexa(altitude);
	return complete_hexa_bytes(res_alt, 1);
}


void Wisol::send_trame(int lat_angle, int lat_minute, double lat_seconde, char lat_c, int lng_angle, int lng_minute, double lng_seconde, char lng_c, int altitude){
	int prec = 5;
  String res;
	res= Wisol::altitude_to_trame_hexa(altitude);
  res += Wisol::dms_lat_to_trame_hexa(lat_c, lat_angle, lat_minute, lat_seconde,prec);
  res+= Wisol::dms_lng_to_trame_hexa(lng_c, lng_angle, lng_minute, lng_seconde, prec);
  Wisol::send_string_data(res);//sending int
}

//parse trame GPS
bool  Wisol::verif_type(String trame){
    return (trame.indexOf("$GPGGA") == 0);
  }

void Wisol::GPGGA_to_DMS(String test, int* angle, int* minute, double* seconde){
  //séparer la partie entière de la partie décimale :
  String angle_minute = test.substring(0, test.indexOf('.'));
  test.remove(0, test.indexOf('.')+1);

  //séparer les angles et les minutes
  int n  = angle_minute.length();
  String s_minute = angle_minute.substring(n-2,n);
  *minute = s_minute.toInt();
  angle_minute.remove(n-2,n);
  *angle = angle_minute.toInt();
  //convertir les secondes
  int temp = test.toDouble();
  *seconde =  (double) (temp*60/100)/100;
  }


void Wisol::trame_GPGGA_to_DMS(String trame, int *lat_angle, int *lat_minute, double *lat_seconde, char* lat_c, int *lng_angle, int *lng_minute, double *lng_seconde, char* lng_c){
if( Wisol::verif_type(trame)) {
  char delimiter = ',';
  int param_suppr = 0;
  String test;
  char buf[20];
  while(param_suppr <=6){
    test = trame.substring(0, trame.indexOf(delimiter));
    if(param_suppr == 2){
      Wisol::GPGGA_to_DMS(test, lat_angle, lat_minute, lat_seconde);
      }
    else if( param_suppr == 4){
      Wisol::GPGGA_to_DMS(test, lng_angle, lng_minute, lng_seconde);
      }
    else if(param_suppr == 3){
      test.toCharArray(buf,20);
     *lat_c = buf[0];
      }
    else if (param_suppr == 5){
      test.toCharArray(buf,20);
      *lng_c = buf[0];
      }
    trame.remove(0, trame.indexOf(delimiter)+1);
    param_suppr+=1;
  }
}
}

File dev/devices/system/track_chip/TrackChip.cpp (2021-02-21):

#include "TrackChip.h"

TrackChip::TrackChip() {
	// Inutile de print ici, la liaison série est initialisée plus tard
	this->gps = new GROVE11302();
	Wire.begin();
	AP_SSID	= "Redmi";
	AP_PWD 	= "toto1234";
}

TrackChip::~TrackChip() {}

void TrackChip::send_data(String s) {
	// Envoyer uniquement des chaines de la forme :
	// 004A882F000398DC2F 

	// insérer vérification

	Wisol wisol = Wisol();
	wisol.send_string_data(s);
}

float TrackChip::get_altitude() {
	static bool init = true; 
	static BMP180I2C bmp = BMP180I2C(BMP_I2C_ADDRESS);

	if (init) {
		bmp.init();
		init = false;
	}

	return bmp.computeAltitude();
}

String TrackChip::get_position() {
	gps->get_data_line();
	String res = (char*) (gps->buffer);

	return res;
}

void TrackChip::connect_to_wifi() {
	Serial.println("connection_to_wifi...");
	Serial.println(AP_SSID);
	Serial.println(AP_PWD);
	
	WiFi.begin(AP_SSID, AP_PWD);
	
	Serial.println("Connecting");
	while(WiFi.status() != WL_CONNECTED) {
		delay(500);
		Serial.print(".");
	}
	
	Serial.println("");
	Serial.print("Connected to WiFi network with IP Address: ");
	Serial.println(WiFi.localIP());
	Serial.println("Setup done");
}

void TrackChip::wifi_scan() {
	Serial.println("Starting scan");
	int wifi_saved = 0;
	uint8_t *bssid;
	char bssid_str[18];
	int power;

	// WiFi.scanNetworks will return the number of networks found
	int n = WiFi.scanNetworks();
	Serial.println("scan done");

	if (n == 0) {
		Serial.println("no networks found");
	} else {
		Serial.print(n);
		Serial.println(" networks found");

    int test_to_delete = 0;
		for (int i = 0; i < n; ++i) {
			
			bssid = WiFi.BSSID(i);
			sprintf(bssid_str, "%X-%X-%X-%X-%X-%X",bssid[5], bssid[4], bssid[3], bssid[2], bssid[1], bssid[0]); 
			power = int(WiFi.RSSI(i));
      
      //Serial.print("test BD google : ");
      //Serial.print(bssid_str[9]);
      //Serial.println(bssid_str[10]);
      
      /*if (test_to_delete < 2){
        Serial.println("enter test to delete");
        for(int k = 0; k<TAILLE_ADRESSE_MAC ;k++){
          //Serial.print("part of MAc is : ");
           bssidtab[test_to_delete][k] = bssid[TAILLE_ADRESSE_MAC-1-k];
           Serial.println(bssidtab[test_to_delete][k]);
          }
          test_to_delete++;
      }*/
			// select fix WiFi which are in google database
			if(bssid_str[9] == 'B' && bssid_str[10] == 'D' && wifi_saved < NB_ADRESSE_MAC){
				for(int k = 0; k<TAILLE_ADRESSE_MAC ;k++){
            Serial.print("part of MAc is : ");
            bssidtab[wifi_saved][k] = bssid[TAILLE_ADRESSE_MAC-1-k];
            Serial.println(bssidtab[wifi_saved][k]);
          };
				mac_address[wifi_saved] = bssid_str;
				recep_power[wifi_saved] = power;
				wifi_saved++;
			}

			// Print SSID, RSSI, BSSID and encryption mode for each network found
			Serial.print(i + 1);
			Serial.print(": ");
			Serial.print(WiFi.SSID(i));
			Serial.print(", Power (dBm) :");
			Serial.print(power);
			Serial.print(", BSSID: ");
			Serial.println(bssid_str);
			
			delay(10);
		}
		delay(5000);	 // Wait for 5s before scanning again
	}
}	

int TrackChip::send_mac_and_get_pos() {
	Serial.println("Posting JSON data to server...");
	
	// Block until we are able to connect to the WiFi access point
	if (WiFi.status() == WL_CONNECTED) {
	
		HTTPClient http;	 
		 
		http.begin(serverAddress);	
		http.addHeader("Content-Type", "application/json");					 
		 
		StaticJsonDocument<256> req;
	
		JsonArray wifiAccessPoints = req.createNestedArray("wifiAccessPoints");

		Serial.println("Filling Json with first wifi object...");
		Serial.println("macAdress : " + mac_address[0]);
		Serial.print("Strength	: ");
		Serial.println(recep_power[0]);
		
		JsonObject wifiAccessPoints_0				= wifiAccessPoints.createNestedObject();
		wifiAccessPoints_0["macAddress"]			= mac_address[0];
		wifiAccessPoints_0["signalStrength"]		= recep_power[0];
		wifiAccessPoints_0["signalToNoiseRatio"]    = 0;

		delay(1000);

		Serial.println("Filling Json with second wifi object...");
		Serial.println("macAdress : " + mac_address[1]);
		Serial.print("Strength	: ");
		Serial.println(recep_power[1]);
		
		JsonObject wifiAccessPoints_1				= wifiAccessPoints.createNestedObject();
		wifiAccessPoints_1["macAddress"]			= mac_address[1];
		wifiAccessPoints_1["signalStrength"]		= recep_power[1];
		wifiAccessPoints_0["signalToNoiseRatio"]    = 0;

		delay(1000);

		Serial.println("Filling Json with third wifi object...");
		Serial.println("macAdress : " + mac_address[2]);
		Serial.print("Strength	: ");
		Serial.println(recep_power[2]);
		
		JsonObject wifiAccessPoints_2				= wifiAccessPoints.createNestedObject();
		wifiAccessPoints_2["macAddress"]			= mac_address[2];
		wifiAccessPoints_2["signalStrength"]		= recep_power[2];
		wifiAccessPoints_0["signalToNoiseRatio"]    = 0;

		delay(1000);
		 
		String requestBody;
		serializeJson(req, requestBody);

		Serial.println("");
		Serial.print(requestBody);
		Serial.println("");
		 
		int httpResponseCode = http.POST(requestBody);

		while(true) {
			if(httpResponseCode>0){
				 
				String response = http.getString(); 

				Serial.println(httpResponseCode);	 
				Serial.println(response);

				// Parse Json response File and get lat, lng and accuracy
				StaticJsonDocument<128> res;
				deserializeJson(res, response);

				location_lat = res["location"]["lat"];
				location_lng = res["location"]["lng"];

				accuracy = res["accuracy"];
				accuracy = accuracy / 50;
				
				return 0;
			} else {
				Serial.printf("Error occurred while sending HTTP POST");
				return -1;
			}
		}
	}

	return -1;
}

uint8_t* TrackChip::get_bssid(int a){
    uint8_t* ret = new uint8_t[TAILLE_ADRESSE_MAC];
    for(int i = 0; i <TAILLE_ADRESSE_MAC ;i++){
      ret[i] = bssidtab[a][i];
      Serial.print(ret[i]);
      Serial.print("-");
    }
    Serial.println("");
    return ret;
  }

String TrackChip::create_message1(){
  char temp[2];
  uint8_t* mac1_addr = this->get_bssid(0);
  int mac1_power = abs(recep_power[0]);
  int altitude = 23;//TrackChip::get_altitude();
  String res = "01";
  Serial.print("taille auth :");
  Serial.println(res.length());
  res+=String(mac1_power);
  /*for (int i = 0; i <TAILLE_ADRESSE_MAC;i++){
    Serial.print(mac1_addr[i]);
    sprintf(temp,"%2X",mac1_addr[i]);
    Serial.print(": ");
    Serial.println(temp);
    Wisol::complete_hexa_bytes(temp, 1);
    res += temp;
    }*/
   res+= TrackChip::part_bssid_to_hexa(mac1_addr);
   res+= String(altitude,HEX);
   res+="00";
   return res;
  }

String TrackChip::create_message2(){
  char temp[2];
  uint8_t* mac2_addr = this->get_bssid(1);
  int mac2_power = abs(recep_power[1]);
  String res = "02";
  res+= String(mac2_power);
  /*for (int i = 0; i <TAILLE_ADRESSE_MAC;i++){
    Serial.print(mac2_addr[i]);
    sprintf(temp,"%2X",mac2_addr[i]);
    Serial.print(": ");
    Serial.println(temp);
    res += temp;
    }*/
   res+= TrackChip::part_bssid_to_hexa(mac2_addr);
   res+="0000";
   return res;
  }
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
